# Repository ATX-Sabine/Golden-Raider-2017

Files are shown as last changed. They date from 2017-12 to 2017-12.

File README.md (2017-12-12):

# The Golden Raider 2017

## The What Now?

The 512th ATX Squadron won the Golden Raider in the November 2017 regionals, and they entrusted me to deck it out with LEDs, music, etc. 

## What's the plan?

We want bridge and engine lighting, an imperial logo shade on the large engine, sound, and basically anything that'll give it that ATX flair.

## OK, How do I learn more?

* [Parts List](./DOCS/PARTS.md)
* [Build Log](./LOGS/)

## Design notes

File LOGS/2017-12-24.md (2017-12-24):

# December 24

Wii remote gets in today, will probably experiment with installing it and the nunchuck and getting button patterns recognized. After that it will just be a bunch of soldering and drilling and getting timings down for lights and sounds.

Note to self: test sounds playing over music, see if there's any problems.

Thinking of redoing the paint job to a black and gold scheme after making the minor repairs.

Note to self: backup the golden raider's SD card regularly to prevent data loss.

---

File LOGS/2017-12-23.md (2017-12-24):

## Dec 23

IT WORKS! THE SX1509 DRIVER WORKS! 

Managed to get it warking on the Onion Omega II by chance then ported it over.

After hours of work, the groundwork is laid, and the Golden Raider Mk II has very few obstacles in its path. As is fitting for a raider.

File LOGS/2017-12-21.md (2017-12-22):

## December 21 2017

Soldered together the speaker bonnet and the GPIO expanders. Just need to solder headers onto to the main computer and we'll be ready to drill speaker and LED holes.

Bonnet tutorials and such:

* https://learn.adafruit.com/adafruit-speaker-bonnet-for-raspberry-pi/raspberry-pi-usage
* https://learn.adafruit.com/playing-sounds-and-using-buttons-with-raspberry-pi/code

Hopefully tonight on stream we'll get sound and some work on the GPIO!

### From the stream

I followed the tutorials and music plays! Now to build a soundController for the raider.

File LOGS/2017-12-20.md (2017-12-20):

## December 20, 2017

Things are starting to move-- got the Adafruit speaker bonnet, speakers, and the 2 GPIO expanders. Plotted where the speakers will go.

The Thursday stream will be the build -- soldering the bonnet and expanders to the onboard computer, getting it set up.

Thinking about upping the paint job a bit...plans will be detailed here once I finalize them.

Working on just straight pythonizing the SX1509 drivers-- wrappers just made me mad.

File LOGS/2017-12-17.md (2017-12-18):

## Dec 17

Making slow progress on the SX1509 driver.

Drilling holes into the bridge for lighting, and planning out the spots for speakers.

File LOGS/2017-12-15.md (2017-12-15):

## December 15th 2017

Ugh, Boost didn't work either. Going to try just a straight port to wiringpy or something.

Still waiting on some supplies before full construction can begin. But plans are being laid. LED spots tested, etc.

Going to look into a shade of gold to match the existing paint, for the scuffs from dissassembly.

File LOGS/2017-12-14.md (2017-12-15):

## Dec 14 2017

Swig is killing me but I'm making slow progress. Might switch to a different method on stream tonight.

Switching to https://github.com/boostorg/python Boost. Needed to fork the orig C++ lib to do so.

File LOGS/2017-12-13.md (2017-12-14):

## Dec 13th 2017

Added login scripts and users to the ship's computer. If the raider ever falls out of ATX hands, the login they'll get is very well locked down so that they don't mess with my systems.

learned about [SWIG and C++] and wrapped an existing C++ module for the SX1509 GPIO expanders with Python, will start testing it tonight to see if it actually, y'know, worked.

The ship's computer board arrived today -- once the extra GPIO expanders get in we'll really get going on construction. Luckily working on spare parts I salvaged from the lab will allow ve to prepare the code and get a good bit of the heavy lifting done without waiting for parts.

Grabbing a breadboard and wires needed to test the SX1509 Python wrapper...

<Insert pic here>

Set up an RGB LED on a SX1509 and adding examples inside the module itself.

UGH compiling swig modules on raspis has had me at it for hours. Documenting the process.

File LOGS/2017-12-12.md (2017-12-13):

# ATX_Sabine's log: 12-12-2017

## Dissassembly completed on the Golden Raider

Both ships sat in carbonite for 48 to undo the major glue points -- the fact that the imperials glue their ships together is not all that surprising.

After freezing, I started with the test ship I nabbed from a particularly trusting stormtrooper -- I think it was Pvt. Rosner. I found that the proper disassembly directions are:

* Remove the bridge
* Remove the side fins
* Seperate the bottom from the top hull
* Pop out the engines

The engines weren't even glued in. Imperials, I tell ya.

I also managed to find a reputable parts smug--er--dealer to get me the new ship computer: A Raspberry Pi Zero W. This will give the Golden Raider Mk 2 aceess to wireless interfaces! I'm excited to mess with the possibilities.

I also have decided upon seondary control systems: 1 or 2 SX1509 GPIO expanders. These will give us the ability to fade lights, control more outputs, and they take surprisingly little power to make.

I'll also need a boatload of LEDs, a stencil to make an imperial shade-- I know, I know, but the Squad comes before my personal artistic tastes-- some speakers, an amplifier that also serves as an audio interface to the ship's main computer (if I'm going to have a creation of mine play that damned march, it'll do it right), and a few other parts-- [DOCS/PARTS.md](../DOCS/PARTS.md) should contain an updated list.

Tonight, I have set up a copy of the ship's main computer, and I'll be detailing the setup for when the Golden Raider's computer arrives.

---

Hm. Seems there's no SX1509 Driver in Python for the Raspi yet. We'll just have to fix that.

Found [WiringPi](https://github.com/WiringPi/WiringPi-Python) to be the best bet for GPIO control library ([API here](https://github.com/WiringPi/WiringPi-Python/blob/master/bindings.i))

Need a new hand drill, ordered one that'll be here shortly.

Decided to add a TTL serial hookup in case I need to get in without wifi or HDMI. Need to figure out how to make it acessible from the outside.

Okay, so the SX1509 DOES have a C++ port, which I can wrap in Python. I've set the C++ port up as a submodule, and that as a submodule of Golden-Raider-2017. Let's just hope using submodules doesn't bite me later...

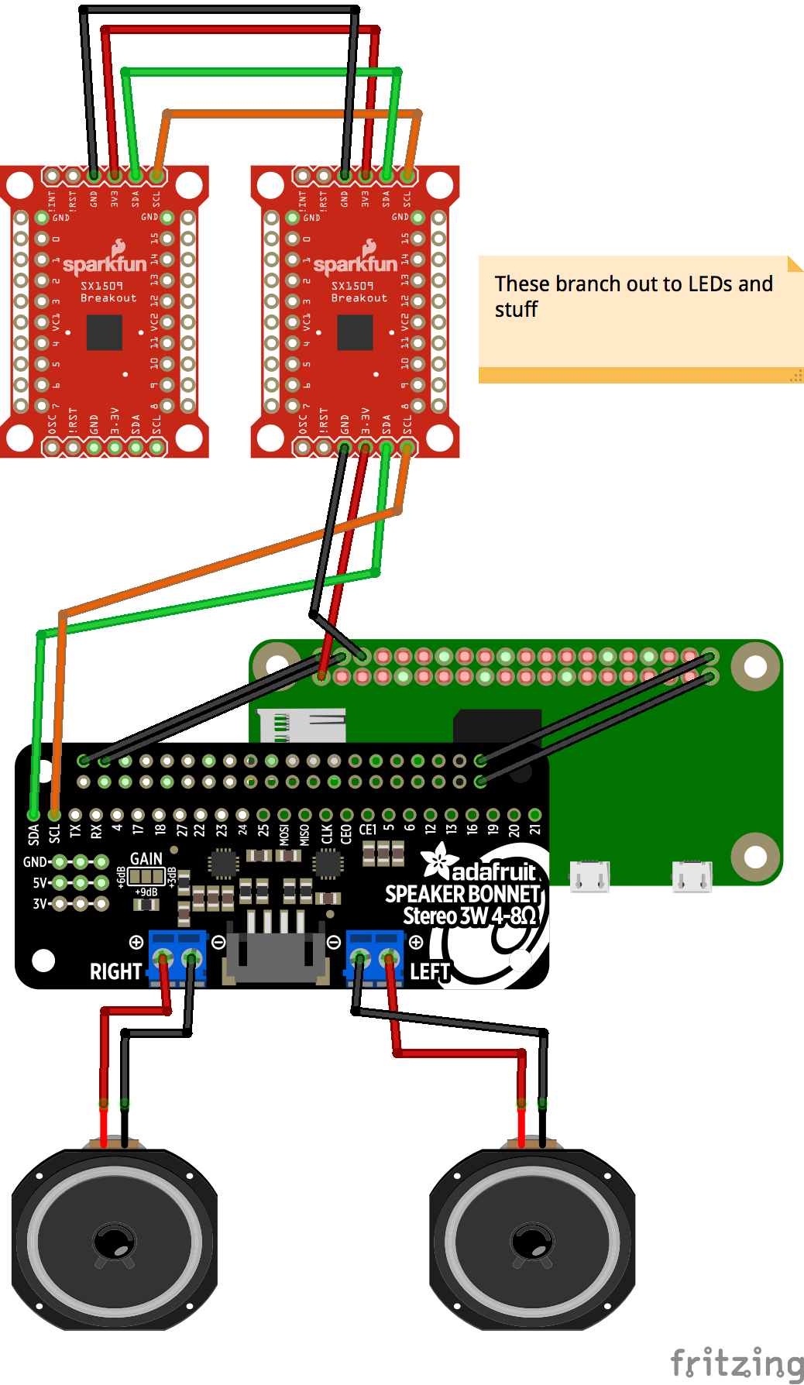
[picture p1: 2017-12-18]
DOCS/SCHEMATICS/Basic-Fritzing.png

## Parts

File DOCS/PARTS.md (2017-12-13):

# Parts Used For Golden Raider Mk 2, with suppliers and costs

## Robotics Parts

These are parts used directly in the assembly of the Golden Raider Mk. 2

| Part Name | Part Description | Part Suppliers | Number Needed | Part Cost (USD) |
| -- | -- | -- | -- | -- |
| Raspberry Pi Zero W | Ship's Main Computer | [Rapberry Pi Org](https://www.raspberrypi.org/products/) | 1 | $10 |
| SX1509 16-GPIO Expander Breakout Board | GPIO PWM Interface for light effects | [SparkFun](https://www.sparkfun.com/products/13601) | 2 | 2 x $4.95 = $9.90 |
| LED- 3W Aluminum PCB (Cool White) | Spotlights on trophy base | [SparkFun](https://www.sparkfun.com/products/13105) | 1 5-pack | $7.95 |
| RGB Common Cathode LEDs | Ship Lights | Lots of places, I used [SparkFun](https://www.sparkfun.com/products/105) | TBD (a lot) | $1.95/ea (Can easily find cheaper) |
| 1-Watt 8Ohm Speaker | To play music and audio effects | Lots of places, I used [SparkFun](https://www.sparkfun.com/products/9151) | 2 | 2 x $1.95 = $3.90 |
| Adafruit I2S 3W Stereo Speaker Bonnet for Raspberry Pi - Mini Kit | Audio interface to ship computer | [Adafruit](https://www.adafruit.com/product/3346) | 1 | $12.95 |

## Tools

The tools I used to got everything set up, assembled, etc. These will come in handy if you're trying to replicate this.

* Diagonal Wire Cutters
* Cell Phone Repair kit (for disassembly of the ship without destroying it)
* Wire strippers
* Pliers
* Soldering Iron
* Hand drill with 0.5mm+ bits
* [USB to TTL converter](https://www.amazon.com/ZYAMY-CP2102-Module-Serial-Downloader/dp/B07784SHF7/)

## Consumables

Various odds n' ends of negligible cost that went towards assembly

* Solder
* Heatshrink Tubing
* 22-gauge solid-core wire
* Couple of PCB's to wire parts together
## Scavenged Parts

Crap I grabbed from my home, or that you probably have lying around or can get secondhand

* Old Wiimote (NOT WiiMotion Plus)

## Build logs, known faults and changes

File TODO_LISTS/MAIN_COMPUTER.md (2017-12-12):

# Setup

- [ ] Flash Firmware to MicroSD Card (Raspbian Stretch)
- [ ] boot w/HDMI cable setup and USB hub to keyboard
- [ ] Change user pi password
- [ ] Connect to WiFi
- [ ] `sudo raspi-config`
  - [ ] set keyboard layout
  - [ ] set locale
  - [ ] enable SSH, I2C
  - [ ] enable serial TTL login
  - [ ] change network name (golden-raider-mk2.local)
- [ ] `sudo apt-get update && sudo apt-get upgrade`
- [ ] reboot headless, ssh in
- [ ] add necessary users and privileges
  - [ ] Sabine_ATX
  - [ ] autopilot
  - [ ] Visitor
    - [ ] Set write privleges to `/etc/wpa_supplicant/wpa_supplicant.config`
- [ ] Remove default `pi` user
- [ ] install necessary dependencies
  - [ ] python3, pip3, wiringpi

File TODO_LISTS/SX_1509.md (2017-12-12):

# SX1509 Module To-Do list

- [ ] Create Module
- [ ] Digital I/O
- [ ] PWM I/O

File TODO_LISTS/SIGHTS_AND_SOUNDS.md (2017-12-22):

[ ] The Imperial
  [ ] Lights turn blue and pulse to the music
  [ ] What music? The Imperial March of course.
  [ ] Shade for the Engine
[ ] The Battle
  [ ] Battle noises
  [ ] Weapons systems engage

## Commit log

2017-12-18 Added Basic Schematic
    [Basic-Fritzing.fzz]
2017-12-24 Added newest version of SX1509 driver
2017-12-25 Buttons AND lights!
2017-12-29 Added common anode RGB LED demo
2018-01-08 Button scan running
2018-01-08 button scanner implemented
2018-01-09 set LED to use enablePWMPin method
2018-01-11 added debounce to wiimote buttons
2018-02-17 Added Resistanc March
